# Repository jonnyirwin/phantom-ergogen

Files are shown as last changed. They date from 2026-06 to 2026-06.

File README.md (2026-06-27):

> ⚠️ **Work in progress — do not build this yet.** The PCB, case, and firmware have not been validated against a physical build. Things will change, things may be wrong. Watch the commits if you want to follow along, but don't order boards from these files yet.

# Eidolon

> **eidolon** /aɪˈdoʊlɒn/ *noun*
> An idealized image; a phantom or spectre of a person or thing.
> — from Greek εἴδωλον *(image, idol, phantom)*

---

A small column-staggered wireless split keyboard. 30 keys (5×3 + 2 thumb per half), Kailh Choc v1 switches, Seeed XIAO nRF52840 BLE, Totem-style clamshell case. Both halves are independent wireless units — no TRRS cable.

## Built on the shoulders of

| Keyboard | Role in this project |
|---|---|
| [**Phantom**](https://github.com/davidphilipbarr/Phantom) by davidphilipbarr | PCB layout source — key positions reverse-engineered from `lephantom.kicad_pcb`; board outline traced from the original `Edge.Cuts`. Eidolon matches the original key centres to < 0.15 mm. |
| [**TOTEM**](https://github.com/GEIGEIGEIST/TOTEM) by GEIGEIGEIST | Case design reference — switch hole dimensions, keycap recess depth, clamshell geometry, and hot-swap socket pocket profiles from the Totem STEP file; the XIAO BLE SMD footprint (`pcb/footprints/xiao_ble.js`) is adapted from Totem's `xiao-ble-smd-cutout`. |
| [**Rufous**](https://github.com/jcmkk3/trochilidae/) by jcmkk3 | Diode placement — diodes sit in each Choc south LED cutout following the Rufous approach. (`pcb/footprints/xiao_pogo.js`, a pogo-pin XIAO mount adapted from Rufous, is kept as an unused alternative to the SMD footprint.) |

## PCB

| Left half | Right half |
|---|---|
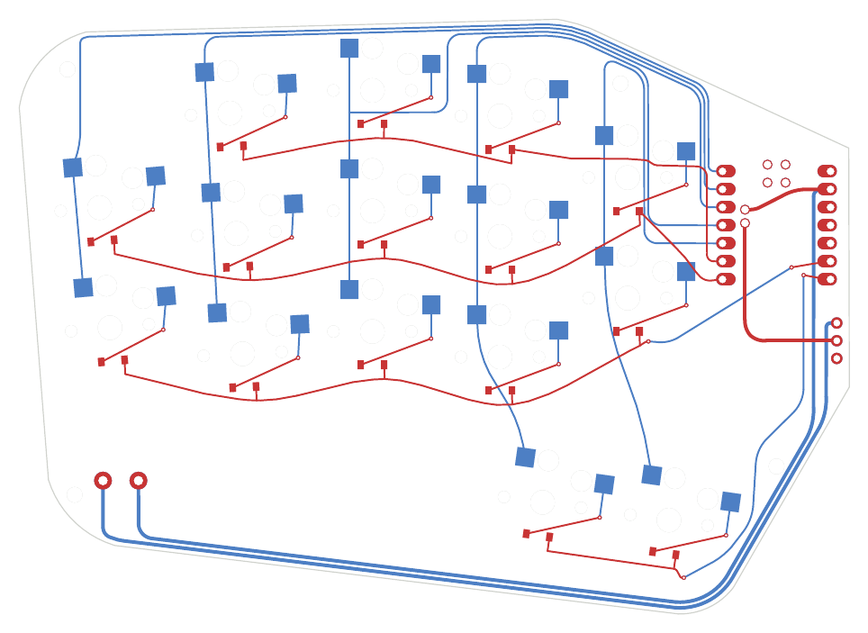
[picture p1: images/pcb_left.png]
Left PCB
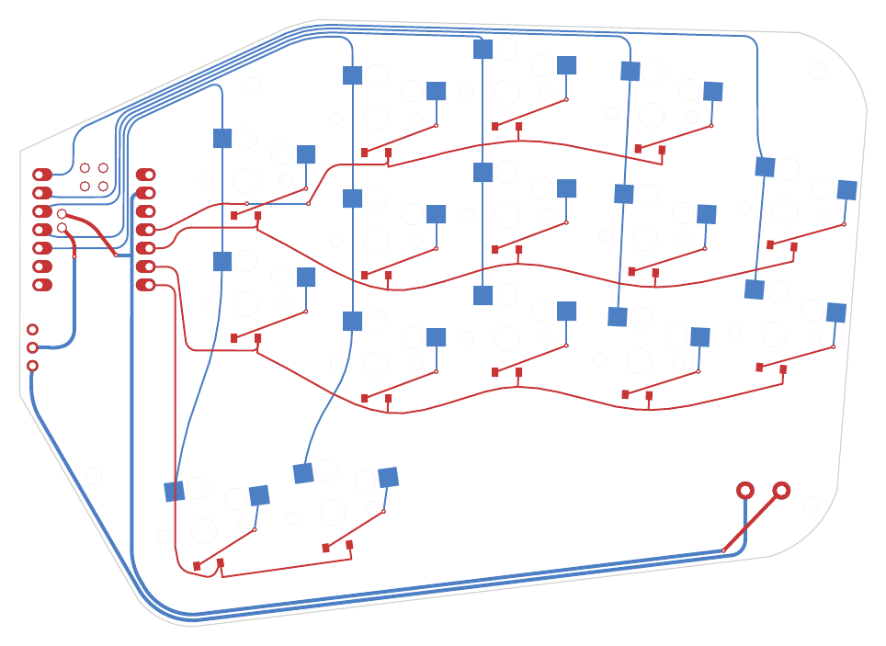
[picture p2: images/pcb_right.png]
Right PCB
|  |  |

## Case

| Top — left | Top — right |
|---|---|
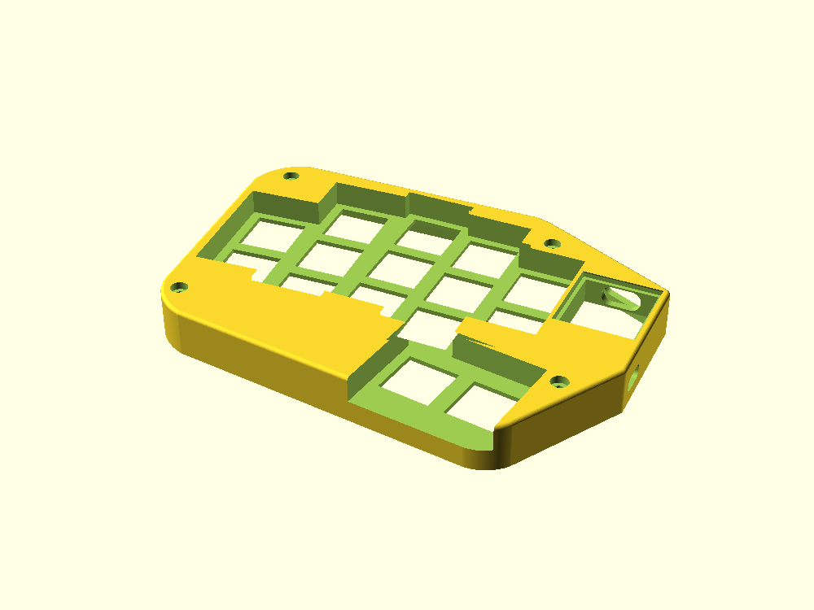
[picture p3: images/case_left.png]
Case top left
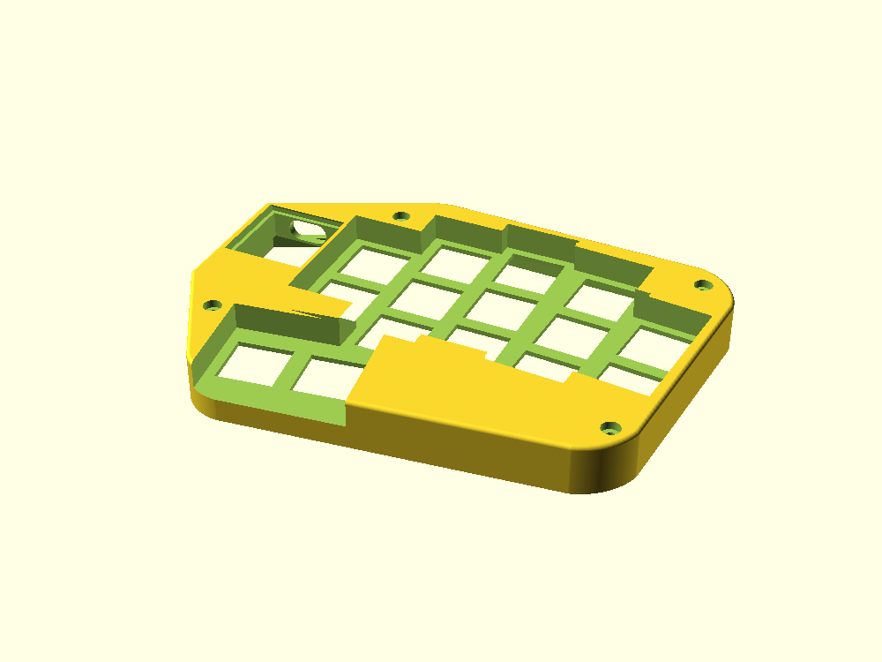
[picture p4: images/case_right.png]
Case top right
|  |  |

| Bottom — left | Bottom — right |
|---|---|
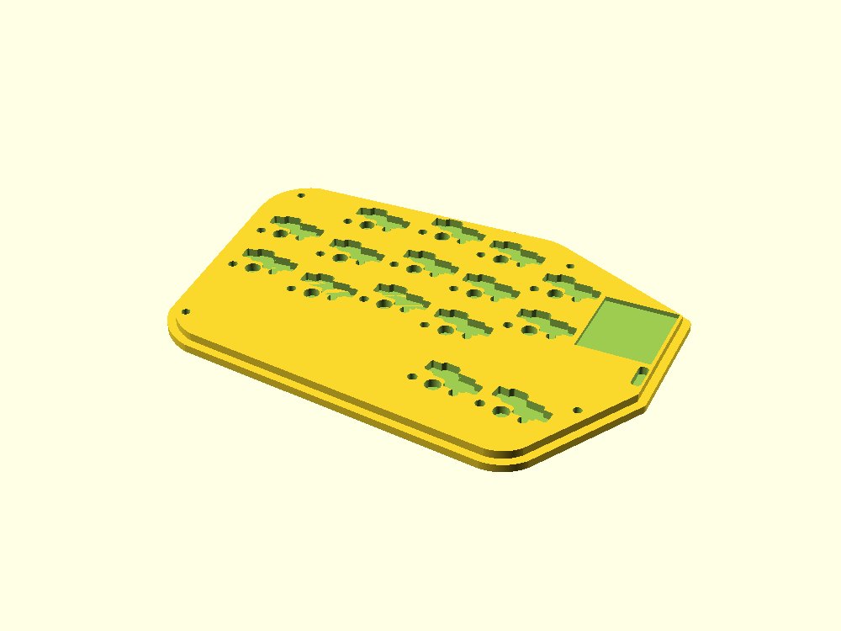
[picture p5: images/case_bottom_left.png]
Case bottom left
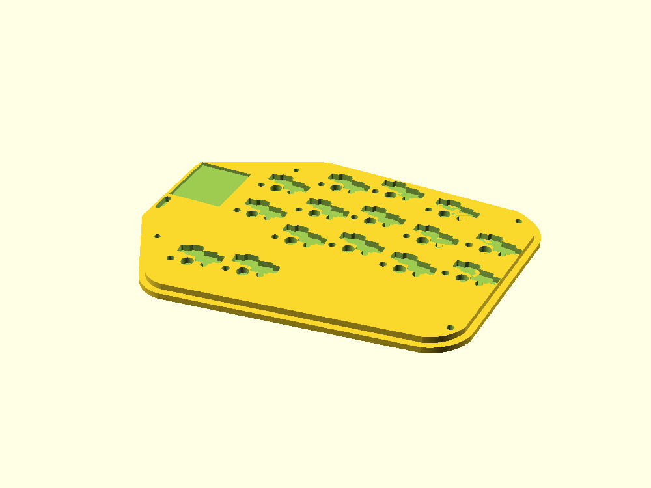
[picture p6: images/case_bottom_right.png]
Case bottom right
|  |  |

---

## Repository layout

```
pcb/              Ergogen source + routed KiCad files + gerbers
  eidolon.yaml      Ergogen config (geometry + nets)
  footprints/       custom Ergogen footprints
  build.js          local build wrapper (injects footprints)
  eidolon_left.kicad_pcb   routed left half
  eidolon_right.kicad_pcb  routed right half
  eidolon_left_gerbers.zip
  eidolon_right_gerbers.zip

case/             OpenSCAD case design
  eidolon_case.scad        top shell (both halves via -D right=true)
  eidolon_case_bottom.scad bottom shell
  stl/                     pre-generated STL files
```

---

## PCB build (Ergogen)

Custom footprints live in `pcb/footprints/`, so use the wrapper rather than the ergogen CLI directly:

```sh
cd pcb
npm install       # once
node build.js     # -> pcb/output/
```

Outputs land in `pcb/output/`:
- `outlines/board_left.svg|dxf`, `board_right.svg|dxf` — board perimeters
- `pcbs/eidolon_left.kicad_pcb`, `eidolon_right.kicad_pcb` — both halves, footprints + nets placed (no routes)

On **ergogen.xyz**, paste each file in `pcb/footprints/` into the web app's Footprints section under its filename (e.g. `reset_button`); `eidolon.yaml` then works as-is.

### Layout

```
 pinky  ring  middle index inner
   ·    top    top   top   ·       (pinky has no top row; inner has no bottom)
 home  home   home  home  upper
 bot   bot    bot   bot   lower
                  thumbL thumbR    (-8°)
```

Pinky splayed 5°, ring splayed 3°; other columns straight. Choc spacing: 18 mm columns, 17 mm rows.

### Wiring — COL2ROW diode matrix (XIAO BLE)

Each half is a fully independent wireless unit (own XIAO + battery, no TRRS), so the two halves carry **independent pin maps**. The columns are identical; the rows are assigned per half to keep each MCU's fan-out clean.

| Matrix | Net | XIAO pin (left) | XIAO pin (right) |
|---|-----|---|---|
| pinky col  | C0 | D0 | D0 |
| ring col | C1 | D1 | D1 |
| middle col | C2 | D2 | D2 |
| index col  | C3 | D3 | D3 |
| inner col  | C4 | D4 | D4 |
| top row | R0 | D5 | D10 |
| home row | R1 | D6 | D9  |
| bottom row | R2 | D8 | D8  |
| thumb row  | R3 | D7 | D7  |

On the right half all four rows sit on the matrix-facing `D7`–`D10` edge (`D5`/`D6` spare), so only the five columns cross the MCU — the physical minimum. **The two halves therefore need different `MATRIX_ROW_PINS` in firmware.**

Power: battery + → `RAW_BATT` → slide switch → `BATT` → XIAO `B+`; battery − → GND.

> **Verify before fab:** the XIAO pad→pin mapping lives in `pcb/footprints/xiao_ble.js` (surface-mount, mounted **face-up** over the PCB). It was corrected and checked against the XIAO datasheet and the TOTEM `xiao-ble-smd-cutout` footprint — re-confirm before ordering.

### Mirrored halves, not reversible

The original Phantom is a single reversible PCB flipped for both hands. Eidolon generates a true left and right board. Because each half is an independent wireless unit with its own firmware, the halves do **not** share a pin map — the right half's `MATRIX_ROW_PINS` differ from the left's (see the per-half table above).

---

## Case (OpenSCAD)

`case/eidolon_case.scad` is the top shell for both halves. The right half is the left mirrored (`-D right=true`).

```sh
openscad -o case/stl/eidolon_case_top_left.stl  case/eidolon_case.scad
openscad -D right=true -o case/stl/eidolon_case_top_right.stl  case/eidolon_case.scad
openscad -o case/stl/eidolon_case_bottom_left.stl  case/eidolon_case_bottom.scad
openscad -D right=true -o case/stl/eidolon_case_bottom_right.stl  case/eidolon_case_bottom.scad
```

Pre-generated STLs are in `case/stl/`.

Top shell features: keycap recess field, stepped 13.8 mm Choc plate holes, XIAO pocket with acrylic window rebate + USB-C cutout, battery pocket, power-switch wall slot, M2 bolt pockets.

### Bottom shell

`case/eidolon_case_bottom.scad` nests inside the top from below. Geometry:

- z ∈ [−2.0, 0]: exterior plate (`floor_t` = 2.0 mm) matching the top case outer footprint
- z ∈ [0, 2.1]: nesting lip; PCB rests on the lip top at z = 2.1
- Per-switch hot-swap socket pockets cut into the lip — traced from the Kailh PG1350 socket silkscreen (plastic body **plus** both SMD pad rectangles), inflated by `socket_clr` = 0.6 mm
- Choc plastic-pin, power-switch-leg, and XIAO underside-joint clearance pockets in the lip
- M2 hex nut pockets (4.0 mm AF × 1.8 mm) at the four bolt positions
- Four Ø8.4 × 1.8 mm bumpon pockets in the underside (≥7.5 mm clear of the nut pockets)

### Mounting hardware

| Part | Spec | Count |
|---|---|---|
| Socket cap bolt | M2 × 12 mm | 4 per half |
| Hex nut | M2 (4.0 mm AF) | 4 per half |

### MCU acrylic window

Cut a piece of 1.5 mm clear acrylic to drop into the XIAO rebate:

| Dimension | Size |
|---|---|
| Width | 20.3 mm |
| Length | 22.8 mm |
| Thickness | 1.5 mm |

Angle the acrylic, slip the +y edge under the square lip (lip A), press the −y edge down past the chamfered lip (lip B). Remove the bottom shell to access the MCU.

---

## Firmware

ZMK firmware for the Eidolon is available at [jonnyirwin/zmk-keyboard-eidolon](https://github.com/jonnyirwin/zmk-keyboard-eidolon).

---

## Deviations from the original Phantom

- **Mirrored L/R** instead of a single reversible board.
- **BLE only** — XIAO nRF52840, COL2ROW diode matrix, battery + slide switch; Pro Micro and TRRS removed.
- **Diodes top-side**, in each Choc south LED gap — hotswap sockets are the only underside component.
- **Trackball omitted.**
- Board outline is the original `Edge.Cuts` polygon with 1.5 mm corner fillets.

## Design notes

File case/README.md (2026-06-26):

# Eidolon Case

> **Warning: the changes listed below have not yet been physically verified. Print and test before ordering in quantity.**

## Changes from original design

### Bottom shell — bumpon pockets

Four 8.4mm diameter × 1.8mm deep pockets added to the bottom face for standard 8mm rubber bumpons. Positions (KiCad coords):

| Location | Position |
|---|---|
| Upper-right (MCU corner) | [141, 38] |
| Lower-right (thumb cluster) | [125, 91] |
| Upper-left | [50, 28] |
| Lower-left | [52, 84] |

All positions have ≥7.5mm clearance from nut pocket edges. The pocket depth matches the nut pockets (`m2_nut_h` = 1.8mm), leaving 0.2mm of floor material below (`floor_t` = 2.0mm).

### Reverted: thicker floor / deeper bolt-head pockets

An earlier revision raised `floor_t` 2.0 → 2.8mm (and `m2_head_h` 2.0 → 3.3mm to keep an M2×12 bolt flush) over a JLC thin-wall flag on the 0.2mm ceiling above the nut pockets. A resin-printed sample showed the thin walls print fine, so both values are reverted to the original design. The bottom floor is back to 2.0mm and M2 bolt heads sit flush with the deck.

## Fit fixes from the resin sample

A resin-printed sample confirmed the top-case switch recesses, M2 bolt recesses/holes
and PCB fit are all good. The following mating features were too tight or missing
clearance and have been corrected (case geometry only — the PCB is unchanged). All
new clearances are biased generous for easy, no-force assembly.

### Bottom shell

- **Hot-swap socket pockets** — the pocket was traced from the socket's *plastic*
  silkscreen only; the two metal SMD solder tabs overhang it by ~2.6mm at each end
  and had no clearance (the socket wouldn't seat). The pocket now cuts the plastic
  body **plus** both pad rectangles, and `socket_clr` is 0.3 → **0.6mm**.
- **Choc v1 plastic-pin pockets** (`switch_pin_pockets`) — new clearance for the
  central pole (Ø4.0) and two locating legs (Ø2.4) that poke below the PCB into the
  lip; previously absent.
- **Power-switch leg pockets** (`power_leg_pockets`) — new clearance slot for the
  three trimmed/soldered through-hole legs below the PCB.
- **XIAO underside-joint pocket** (`xiao_underside_pocket`) — shallow 1.2mm recess
  in the lip under the XIAO so its castellation fillets and the BAT/GND access-hole
  solder joints don't bear on the solid lip.

### Top shell

- **XIAO cavity** — was `20.0 × 17.5mm`, *smaller than the 21.0 × 17.78mm board*.
  Now board size + `xiao_clr` 0.4 → **0.6mm**/side (≈ 19.0 × 22.2mm window).
- **USB-C cutout** — was tight; now **+1.5mm wide** (9.0 → 10.5) and **+1.5mm tall**
  (4.0 → 5.5). Bottom edge unchanged, so the lip below stays ~1.75mm.
- **Power-switch body** — the visible rounded slot in the wall is unchanged (8 × 4mm).
  The switch body (just over 9mm wide, overhanging the PCB edge ~0.5mm) wouldn't fit,
  so a separate internal `power_body_pocket` (11mm) clears it; it reaches into the
  wall for the overhang and **merges with the XIAO cavity** (no dividing wall — the
  body and XIAO drop into one continuous opening, which also eases insertion). The
  body sits below the acrylic rebate, so the cover's top retention lip is preserved.

### Assembly notes (no case change)

- **XIAO** mounts flush on the PCB top via **castellated edge half-holes** (solder at
  the board edge, no under-board reflow). Its underside **BAT+/BAT− pads must be
  soldered up through the PCB access holes** beneath them — this completes the
  battery/charge path (the copper routing to the switch and battery pads is already
  present).
- **Battery**: solder the LiPo leads to the two battery pads (+ = RAW_BATT,
  − = GND, 5mm pitch). No jumper to the XIAO is needed.

## Remaining known issues (unresolved)

- `plate_t16 = 0.75mm` — the thin switch plate counterbore section under each switch hole. May be flagged by JLC depending on print process.
- `lip_t = 0.6mm` — acrylic retention lips on the XIAO cover slot. Thin for FDM; may need increasing if not printing in resin.

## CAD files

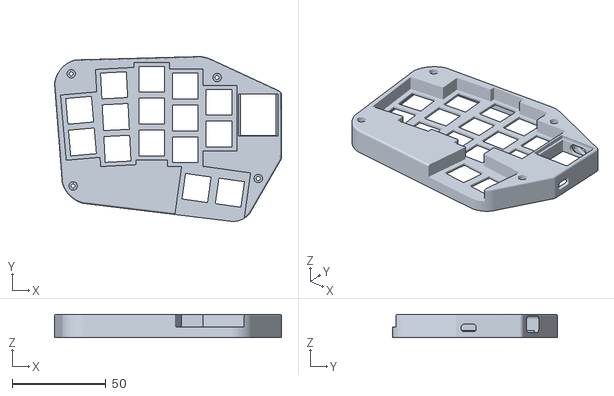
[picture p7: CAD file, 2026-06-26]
case/stl/eidolon_case_top_left.stl
121.4 x 88.2 x 12.5

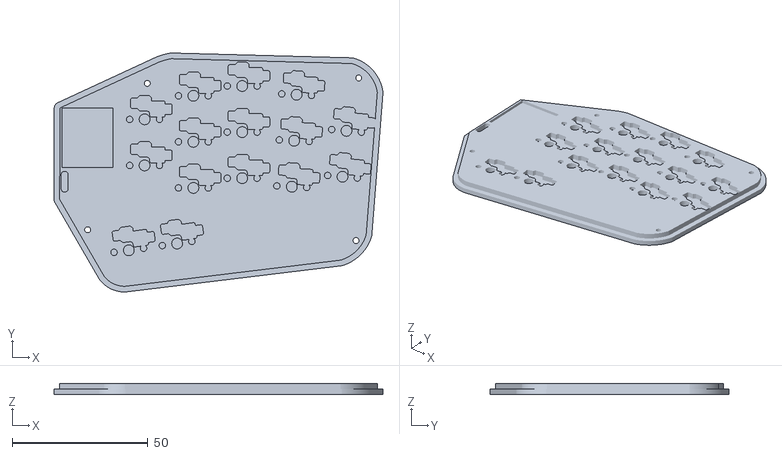
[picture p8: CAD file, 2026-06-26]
case/stl/eidolon_case_bottom_right.stl
121.4 x 88.2 x 4.10

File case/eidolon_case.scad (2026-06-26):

// Eidolon case — BOTH halves (left geometry; right = mirrored build).
// Outline from the PCB Edge.Cuts of lephantom.kicad_pcb (6 lines + 5 arcs,
// exact mm coordinates) plus the two routing reliefs now carried by BOTH
// ergogen PCBs (P1/P2 top edge -0.3mm, P10/P11 pinky edge -0.7mm), so the two
// boards are exact mirror images and one case design fits both. The case
// footprint is the PCB outline grown outward by (gap + wall) so the PCB drops
// inside the walls:
//   gap  = 0.15mm clearance between PCB edge and inner wall
//   wall = 2.0mm  case wall thickness
// then extruded. This pass produces the solid outer shape only.
//
//   openscad -o eidolon_case_top_left.stl  case/eidolon_case.scad
//   openscad -D right=true -o eidolon_case_top_right.stl case/eidolon_case.scad
//
// Right-half fit (verified against the routed ergogen boards): every
// footprint origin mirrors exactly (x_left + x_right = 170, same y), and the
// four case bolts ARE the PCB mounting holes. The XIAO keeps its orientation
// under the PCB mirror, but its position mirrors and the pocket/USB cutout
// are symmetric about the pocket axis, so the mirrored case still fits; the
// power switch flips orientation but its body centre and actuator height are
// unchanged, so the mirrored wall slot lines up.
right = true;   // build the right-half case (mirror of the left)

gap    = 0.15;   // PCB-to-inner-wall clearance (per side)
wall   = 2.0;    // case wall thickness
height = 12.5;   // extrusion depth (mm) — matches Totem top shell
switch = 13.8;   // Choc switch plate cutout (mm square) — Kailh spec / Totem STEP
// Per-column keycap recess. Depth/corner from Totem STEP; opening sized to the
// keycap (not the switch) so caps drop in without catching. At 18mm column pitch
// an 18mm cap leaves no rib, so adjacent column recesses merge into field pockets
// (as on the Totem, whose real recesses are big multi-column pockets).
recess_d = 6.85; // recess depth from top (rim->switch-plate in Totem)
keycap_x = 18.0; // keycap footprint, horizontal
keycap_y = 17.0; // keycap footprint, vertical
key_clr  = 0.5;  // extra clearance per side so caps don't catch
recess_r = 0;  // recess corner fillet
// Widen the recess on the RIGHT of the two leftmost columns (pinky+ring) by
// widen_f, extending them toward the next column to close the inter-column ribs.
// Top switches of the pinky+ring columns (the ones bordering the ribs); the
// bottom switch of each column (9, 11) is left at normal width.
widen_keys = [4, 1, 6];        // pinky-top, ring-top, ring-middle
widen_f    = 0.25;             // +25% width, added entirely on the right
// Stepped switch hole + plate (Totem STEP): below the recess floor sits a thin
// plate carrying the switch. The hole is 13.8mm for plate_t13 then opens to a
// 16mm counterbore for plate_t16; below the plate is a cavity for the PCB.
plate_t13 = 1.2;   // 13.8mm hole depth (upper, switch clips here)
plate_t16 = 0.75;  // 16mm counterbore depth (lower)
cbore     = 16.0;  // counterbore size
// derived z-levels (z=0 bottom, z=height top) — defined here so usb_z0 can use them
plate_top = height - recess_d;                 // recess floor / plate top (5.65)
plate_bot = plate_top - plate_t13 - plate_t16; // plate underside (3.70)
// XIAO BLE microcontroller — walled pocket on the right, a hole straight through
// the case (separate from the keycap recess). At the top (-y) end the slanted
// outer wall is flattened by a rounded-rectangular recess, and the USB-C socket
// cutout pierces that flat into the pocket. The PCB right edge is grown by
// pcb_pad (see outline) so the pocket has board under it + real walls.
xiao_l   = 21.0;           // board length (long axis, vertical / y) — footprint outline
xiao_w   = 17.8;           // board width (x) — footprint outline
xiao_clr = 0.6;            // clearance per side inside the pocket
xiao_pos = [137.0, 44.0];  // pocket center, KiCad coords — up near the top angle
xiao_rot = 0;              // deg; 0 = level with the right edge
// USB-C side: a rounded-rect recess cut into the top-right wall makes a flat
// face usb_wall in front of the pocket; the socket cutout goes through it.
flat_w   = 14.0;           // flat recess width  (x)
flat_h   = 9.0;            // flat recess height (z)
flat_r   = 2.0;            // flat recess corner radius
usb_wall = 2.0;            // wall left between the flat face and the pocket
usb_w    = 10.5;           // USB-C cutout width  (+1.5 from 9.0)
usb_h    = 5.5;            // USB-C cutout height (+1.5 from 4.0); lip below = 1.75mm
// SMD-mounted XIAO (castellated on PCB top): XIAO board sits on plate_bot with
// its own 1.0mm thickness, then the USB-C connector body extends ~3.16mm above
// that. Connector top is at plate_bot + 1.0 + 3.16 = plate_bot + 4.16. Place
// the cutout bottom 0.3mm below the XIAO PCB top to clear the connector body.
usb_z0   = plate_bot + 0.7;
// Acrylic cover over the XIAO through-hole: shallow rebate in the top deck,
// acrylic drops in flush with the deck top and rests on a ledge round the
// pocket. With SMD mount there's no MCU bump, so the rebate sits in the deck.
acrylic_t     = 1.5;       // acrylic thickness
acrylic_ledge = 1.0;       // ledge each side (rebate footprint > pocket footprint)
// Retention lips: deck material above the acrylic on the +/-y short ends that
// overhangs by lip_overhang, capturing the acrylic. One-time install: angle
// the acrylic to slip one short edge under one lip, then bow the acrylic
// slightly to push the other short edge past the second lip.
lip_t       = 0.6;        // lip vertical thickness (~3 print layers at 0.2mm)
lip_overhang= 0.8;        // lip A inward projection (full flat); lip B same width
                          // but flat for lip_b_flat with the rest chamfered.
lip_b_flat  = 0.4;        // lip B's flat retention width at the inner end
                          // (lip_overhang - lip_b_flat = chamfer width)
// Battery pocket — 301230 LiPo cell (3.0 x 12 x 30 mm) sits ON TOP of the PCB
// in the empty palm-rest area, hidden between the PCB and the underside of the
// deck. Pocket is cut UPWARD from plate_bot through the plate into the deck so
// the cell drops in from below before the PCB is seated; wires bend up to F.Cu
// pads on the PCB top (5mm apart, see footprints/battery.js). Bottom of the
// pocket is open to the under-PCB cavity (which the bottom shell will close).
bat_pos    = [59.625, 80.0]; // KiCad — palm-rest area, clear of every keycap pad
bat_rot    = 0;              // long axis along x (-90 = along y)
bat_x      = 38.75;          // pocket: 301230 cell (30) + 0.5 at +x + 8.25 wire
                             // well at -x. The well must hold the pad pair's
                             // 8.5mm copper span (TOTEM 5mm pitch, 2.5mm pads):
                             // moving the pads instead doesn't work — east puts
                             // pad-2 solder under the cell (0.25 margin), west
                             // pokes pad 1 out the wall. -x wall at 40.25 keeps
                             // 0.5 to pad-1 copper and 1.15 to the BL bolt shaft
bat_y      = 14.0;           // pocket width (cell 12 + 1mm each side)
bat_depth  = 3.5;            // cell + 0.5 clearance above plate_bot
// MSK-12D19 power switch — through-hole SPDT on the PCB right edge with the
// actuator overhanging. The case needs a slot in the right wall for the
// actuator/slider; sized for 1.5mm slider travel + clearance.
sw_pos   = [145.5, 60.27]; // switch centre, KiCad — matches ergogen power placement
sw_z     = plate_bot + 1.5;// slot vertical centre = actuator height above the PCB
// The switch body is just over 9mm wide along the wall and overhangs the PCB edge
// by 0.5mm, so the slot must clear the full body width — wider than the gap to the
// XIAO cavity. The pocket therefore MERGES into the XIAO cavity (no dividing wall).
// The body sits at z = [plate_bot, ~plate_bot+4], below the acrylic rebate, so the
// cover's top retention lip is preserved.
sw_slot_w = 8.0;           // visible actuator slot width (y) — rounded, original size
sw_slot_h = 4.0;           // slot height (z) — original; the side hole itself was fine
sw_slot_inward = 5.0;      // how much the slot extends into the case body (-x)
// The switch body is just over 9mm wide and overhangs the PCB edge ~0.5mm. It's
// cleared by a separate INTERNAL body pocket (power_body_pocket) that stays inboard
// of the outer wall — so the visible slot keeps its rounded look — and whose flat
// -y edge overlaps the XIAO cavity so the two voids merge without a coincident fin.
sw_body_w = 11.0;          // body 9.2 + clearance; flat -y edge (54.77) overlaps the
                           // XIAO cavity edge (55.1) by ~0.33mm at every z
sw_body_h = 4.5;           // body height above the PCB top
// M2 socket-cap case bolts at 4 corners (KiCad coords). Head sinks into a
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

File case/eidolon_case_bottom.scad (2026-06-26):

// Eidolon case — BOTTOM SHELL.
// Nests inside eidolon_case.scad. Sits below the PCB and pushes it up against
// the top case's plate. Shares outline / switches / bolts / plate_bot with
// the top SCAD via `include` (SUPPRESS_TOP=true skips the top render).
//
//   openscad -o eidolon_case_bottom_left.stl case/eidolon_case_bottom.scad
//
// Geometry (z-up, KiCad y-down — final mirror flips y):
//   z ∈ [-floor_t, 0] : exterior plate, outer = outline + gap + wall, matches
//                       the top case outer so the seam at z=0 is flush.
//   z ∈ [0, lip_h]    : nesting lip, outer = outline + gap - fit_clr, slips
//                       into the top case cavity from below.
//   lip_h = plate_bot - pcb_t = 2.10mm  (PCB underside rest plane).
// Cutouts:
//   - Kailh PG1350 hot-swap socket pockets at each switch — TOTEM silkscreen
//     outline (Z-shape, two bulges). The pockets cut all the way through the
//     lip (z=0 → z=lip_h) so a 1.8mm-tall socket fits, but the exterior
//     plate seals them at the bottom, so the sockets are not visible from
//     outside. Socket bottom ends ~0.3mm above the floor top.
//   - M2 hex-nut pockets in the bottom face at the four corner bolts.
//   - M2 shaft holes through the whole shell.

SUPPRESS_TOP = true;
include <eidolon_case.scad>;

// === bottom-shell dimensions ===
pcb_t           = 1.6;                 // PCB thickness
floor_t         = 2.0;                 // exterior plate below z=0 (2mm min wall)
lip_h           = plate_bot - pcb_t;   // 2.10mm — nesting lip top = PCB underside
fit_clr         = 0.1;                 // lip-to-top-case-cavity slip clearance

// Kailh PG1350 hot-swap socket body outline in switch local frame, traced from
// TOTEM's Kailh_socket_PG1350_optional.kicad_mod silkscreen — a Z-shape with
// two rectangular bulges (one around each SMD pad) connected by curves. Pads
// are at (-3.275, -5.95) and (8.275, -3.75). The polygon hugs the body; a
// small inflation by socket_clr is applied at use to give plastic clearance.
socket_outline = [
    [-2.0,    -4.2  ], [-2.0,    -7.7  ],
    [-1.5,    -8.2  ], [ 1.5,    -8.2  ],
    [ 2.0,    -7.7  ], [ 2.0,    -6.7  ],
    [ 2.1464, -6.3464],                     // arc midpoint (lower inner corner)
    [ 2.5,    -6.2  ], [ 7.0,    -6.2  ],
    [ 7.0,    -1.5  ], [ 2.5,    -1.5  ],
    [ 2.5,    -2.2  ],
    [ 2.0607, -3.2607],                     // arc midpoint (upper inner corner)
    [ 1.0,    -3.7  ], [-1.5,    -3.7  ]
];
socket_clr = 0.6;  // inflate the outline by this much for socket plastic+metal slop

// M2 hex nut: 4.0mm across flats. Hex circumradius = 4/√3 ≈ 2.31, plus slack.
m2_nut_af = 4.0;
m2_nut_h  = 1.8;   // nut thickness; pocket depth from the bottom face upward

module bottom_body()
    union() {
        translate([0, 0, -floor_t])
            linear_extrude(floor_t)
                offset(r = gap + wall) polygon(outline);
        linear_extrude(lip_h)
            offset(r = gap - fit_clr) polygon(outline);
    }

// === clearance pockets cut into the lip (z = 0 .. lip_h) ===
// All of the below pierce the full lip height so parts protruding below the PCB
// fit; the exterior floor seals the cuts from outside. Straight (no chamfer) —
// the fit is set by clearance alone.

// Hot-swap socket pocket footprint: the hand-traced plastic body PLUS the two
// metal SMD solder tabs (2.6mm sq at the pad centres), which overhang the plastic
// by ~2.6mm at each end and previously had no clearance. socket_clr inflates it.
// The sockets do NOT mirror on the right-half PCB, but the footprint is chiral, so
// for the right build the profile is mirrored LOCALLY and the global mirror([1,0,0])
// cancels it — leaving the pocket in the physical socket's chirality.
sock_pad_d = 2.6;
sock_pads  = [[-3.275, -5.95], [8.275, -3.75]];
module socket_full() {
    polygon(socket_outline);
    for (p = sock_pads) translate(p) square(sock_pad_d, center = true);
}
module socket_2d() {
    if (right) mirror([1, 0]) offset(r = socket_clr) socket_full();
    else                      offset(r = socket_clr) socket_full();
}
module socket_pockets()
    for (s = switches)
        translate([s[0], s[1], 0])
            rotate([0, 0, -s[2]])
                linear_extrude(lip_h + 0.02) socket_2d();

// Choc v1 plastic protrusions poking below the PCB: central pole + two locating
// legs, on the switch y=0 axis. (The electrical pin holes sit inside the socket
// pocket already, so only these three plastic features need clearing.)
pole_d = 4.0;   // central pole Ø3.429 + clearance
leg_d  = 2.4;   // locating legs Ø1.702 + clearance
module switch_pins_2d() {
    circle(d = pole_d, $fn = 64);
    translate([ 5.5, 0]) circle(d = leg_d, $fn = 48);
    translate([-5.5, 0]) circle(d = leg_d, $fn = 48);
}
module switch_pin_pockets()
    for (s = switches)
        translate([s[0], s[1], 0])
            rotate([0, 0, -s[2]])
                linear_extrude(lip_h + 0.02) switch_pins_2d();

// MSK-12D19 trimmed-leg clearance: the 3 through-hole legs (2.5mm pitch along y)
// protrude below the PCB into the lip. Rounded slot at sw_pos; the global mirror
// handles the right build, as with power_slot().
module power_legs_2d()
    offset(r = 1.0) square([0.5, 5.5], center = true);   // -> 2.5 x 7.5 rounded
module power_leg_pockets()
    translate([sw_pos[0], sw_pos[1], 0])
        linear_extrude(lip_h + 0.02) power_legs_2d();

// XIAO underside solder-joint clearance: shallow recess in the lip top under the
// XIAO so the castellation fillets and the BAT/GND access-hole joints (soldered up
// through the PCB) don't bear on the solid lip. Leaves ~0.9mm of lip below.
xiao_uj_depth = 1.2;
module xiao_underside_pocket()
    translate([xiao_pos[0], xiao_pos[1], lip_h - xiao_uj_depth])
        rotate([0, 0, -xiao_rot])
            linear_extrude(xiao_uj_depth + 0.02)
                square([xiao_w + 1, xiao_l + 1], center = true);

// Hex nut pockets in the bottom face (z = -floor_t), m2_nut_h deep upward.
module nut_pockets()
    for (b = bolts)
        translate([b[0], b[1], -floor_t - 0.01])
            linear_extrude(m2_nut_h + 0.01)
                circle(r = m2_nut_af / sqrt(3) + 0.07, $fn = 6);

// Bolt shaft holes — all the way through so the bolt can engage the nut.
module bolt_shafts()
    for (b = bolts)
        translate([b[0], b[1], -floor_t - 1])
            linear_extrude(lip_h + floor_t + 2)
                circle(d = m2_shaft_d, $fn = 96);

// Bumpon (rubber foot) pockets — 8.4mm dia, on the bottom face.
// Same depth as the nut pockets (m2_nut_h), leaving 0.2mm of floor below.
bumpon_d     = 8.4;
bumpon_depth = m2_nut_h;
bumpons = [
    [141,  38],   // upper-right — MCU corner
    [125,  91],   // lower-right — thumb cluster corner
    [ 50,  28],   // upper-left  — 7.7mm from TL bolt, 9.5mm from top wall
    [ 52,  84],   // lower-left  — 7.5mm from BL bolt, 15mm from left wall
];

module bumpon_pockets()
    for (b = bumpons)
        translate([b[0], b[1], -floor_t - 0.01])
            linear_extrude(bumpon_depth + 0.01)
                circle(d = bumpon_d, $fn = 96);

module bottom_case()
    mirror([0, 1, 0])
        difference() {
            bottom_body();
            socket_pockets();
            switch_pin_pockets();
            power_leg_pockets();
            xiao_underside_pocket();
            nut_pockets();
            bolt_shafts();
            bumpon_pockets();
        }

// Preview: render top + bottom together for fit check. EXPLODED > 0 lifts the
// top by that many mm; 0 = fully assembled. `right` (from the included top
// SCAD, or -D right=true) mirrors the build for the right half:
//   openscad -D right=true -o eidolon_case_bottom_right.stl case/eidolon_case_bottom.scad
PREVIEW  = false;
EXPLODED = 6;

module bottom_build() {
    if (PREVIEW) {
        bottom_case();
        translate([0, 0, EXPLODED]) top_case();
    } else {
        bottom_case();
    }
}

if (right) mirror([1, 0, 0]) bottom_build();
else bottom_build();

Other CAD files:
case/stl/eidolon_case_top_right.stl
case/stl/eidolon_case_bottom_left.stl

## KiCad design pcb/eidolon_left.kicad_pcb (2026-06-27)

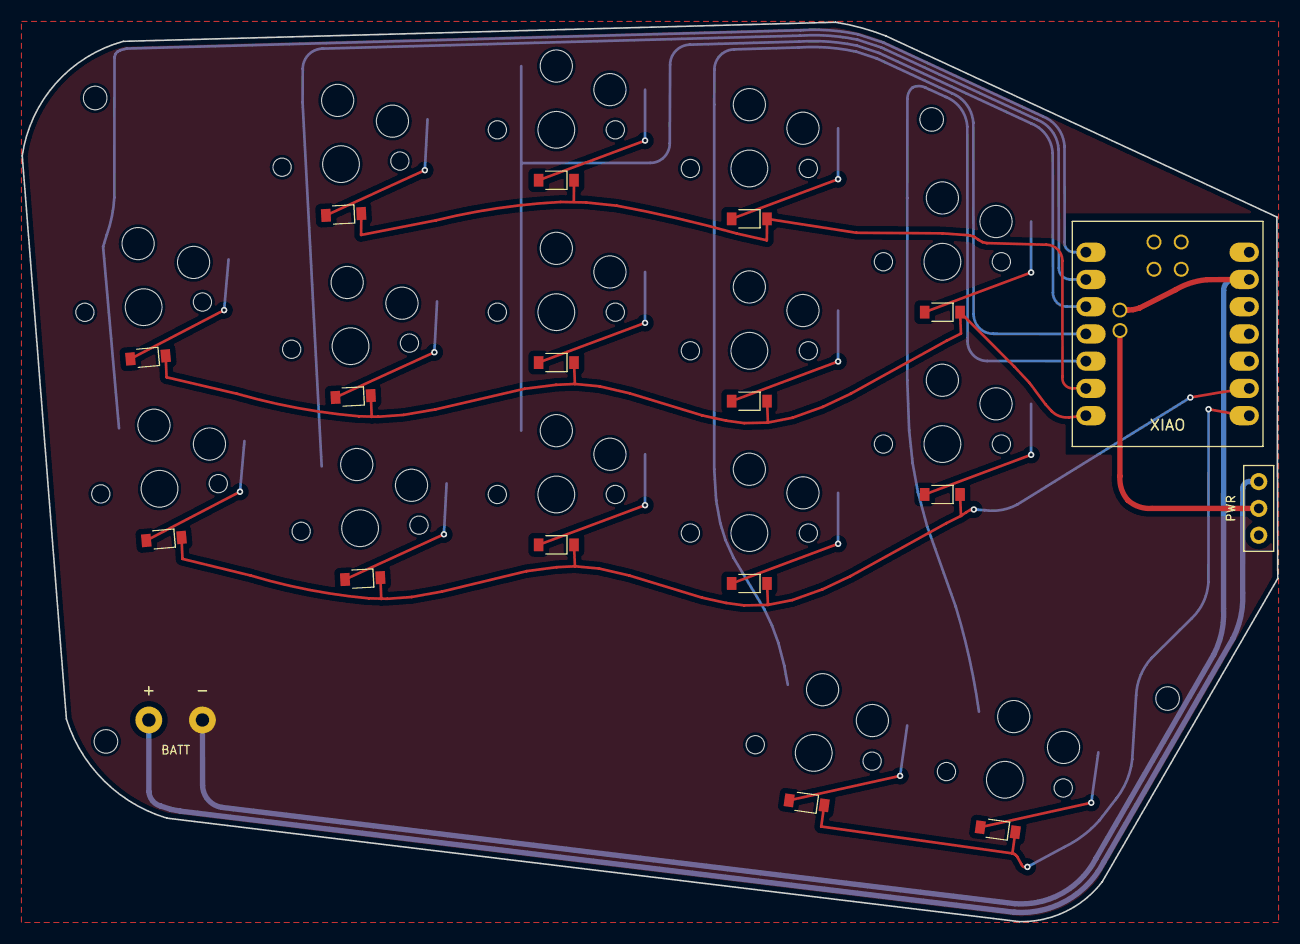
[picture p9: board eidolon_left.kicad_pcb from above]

Board: 2 copper layers, 117.1 x 83.9 mm, 37 parts (0 on the bottom side), 27 nets.

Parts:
BT1: battery_pads
D1, D2, D3, D4, D5, D6, D7, D8, D9, D10, D11, D12, D13, D14, D15: diode_sod123
MCU1: xiao_ble
MH1, MH2, MH3, MH4: mounting_hole_m2
S1, S2, S3, S4, S5, S6, S7, S8, S9, S10, S11, S12, S13, S14, S15: PG1350
SW1: power_switch_spdt

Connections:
BATT: MCU1.BAT, SW1.2
C0: MCU1.1, S12.1, S13.1
C1: MCU1.2, S9.1, S10.1, S11.1
C2: MCU1.3, S1.1, S2.1, S3.1
C3: MCU1.4, S4.1, S5.1, S6.1, S14.1
C4: MCU1.5, S7.1, S8.1, S15.1
GND: BT1.2, MCU1.13, MCU1.GND
R0: D3.2, D6.2, D11.2, MCU1.6
R1: D2.2, D5.2, D8.2, D10.2, D13.2, MCU1.7
R2: D1.2, D4.2, D7.2, D9.2, D12.2, MCU1.9
R3: D14.2, D15.2, MCU1.8
RAW_BATT: BT1.1, SW1.1
matrix_index_bottom: D4.1, S4.2
matrix_index_home: D5.1, S5.2
matrix_index_top: D6.1, S6.2
matrix_inner_bottom: D7.1, S7.2
matrix_inner_home: D8.1, S8.2
matrix_middle_bottom: D1.1, S1.2
matrix_middle_home: D2.1, S2.2
matrix_middle_top: D3.1, S3.2
pinky_pinky_bottom: D12.1, S12.2
pinky_pinky_home: D13.1, S13.2
ring_ring_bottom: D9.1, S9.2
ring_ring_home: D10.1, S10.2
ring_ring_top: D11.1, S11.2
thumb_left_thumb: D14.1, S14.2
thumb_right_thumb: D15.1, S15.2

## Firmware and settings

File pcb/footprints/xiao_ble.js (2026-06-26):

// Seeed XIAO BLE (nRF52840) surface-mount castellated footprint.
// Adapted from GEIGEIGEIST/TOTEM v0.3 "xiao-ble-smd-cutout.kicad_mod":
//   - 14 thru-hole oval pads at x=±7.62, 2.54mm pitch, drill 1mm with the
//     drill OFFSET 0.475 toward the board center -> half-holes for soldering
//     to the XIAO's castellated edge, while keeping a normal copper pad on
//     the inside that can route on either layer.
//   - 4 inner thru-hole pads near the USB end aligning with the XIAO's underside
//     SWD debug group (SWDIO / SWCLK / RESET / GND). Left UNCONNECTED here --
//     access holes only. (Verified against GEIGEIGEIST/TOTEM: these are the
//     debug pads, NOT the battery -- an earlier revision had this backwards.)
//   - 2 thru-hole pads at the side reaching the XIAO underside BAT + GND -- this
//     is the actual battery connection (cell -> power switch -> BATT -> here).
//
// Local frame: USB end at -y, far end at +y. XIAO is mounted FACE-UP on top
// of the keyboard PCB so component-side pins map directly (no x-mirror).
// The existing Phantom config uses rotate: 0, which puts the XIAO USB toward
// the KiCad -y direction (top-right of the source PCB) — this matches.
//
// Net mapping (face-up XIAO, USB at local -y):
//   left col  (x = -7.62), -y -> +y:  D0 D1 D2 D3 D4 D5 D6
//   right col (x = +7.62), -y -> +y:  5V GND 3V3 D10 D9 D8 D7
// The power pins (5V/GND/3V3) cluster at the USB end (-y); D7 is the far-corner
// pin, adjacent to D6 across the bottom edge. (An earlier revision had this
// column reversed -- D7 at the USB end, 5V at the far end -- which put VBUS on a
// matrix row and 5V/GND onto GPIOs. Fixed.)
module.exports = {
  params: {
    designator: 'MCU',
    side: 'F',
    P5V: { type: 'net', value: 'P5V' },
    GND: { type: 'net', value: 'GND' },
    P3V3: { type: 'net', value: 'P3V3' },
    BAT: { type: 'net', value: 'BAT' },
    D0: { type: 'net', value: 'D0' }, D1: { type: 'net', value: 'D1' },
    D2: { type: 'net', value: 'D2' }, D3: { type: 'net', value: 'D3' },
    D4: { type: 'net', value: 'D4' }, D5: { type: 'net', value: 'D5' },
    D6: { type: 'net', value: 'D6' }, D7: { type: 'net', value: 'D7' },
    D8: { type: 'net', value: 'D8' }, D9: { type: 'net', value: 'D9' },
    D10: { type: 'net', value: 'D10' }
  },
  body: p => {
    // castellated half-hole: drill offset 0.475mm toward board centre (+x for
    // left col, -x for right col), so the drilled cylinder breaks out as a
    // half-cylinder on the board edge.
    const cast = (name, x, y, net) => {
      const off = x < 0 ? '0.475 0' : '-0.475 0';
      return `(pad "${name}" thru_hole oval (at ${x} ${y} ${p.r}) (size 2.75 1.8) (drill 1 (offset ${off})) (layers *.Cu *.Mask) ${net})`;
    };
    // inner access hole: small thru-hole 1.397 dia, 1.016 drill
    const access = (name, x, y, net) =>
      `(pad "${name}" thru_hole circle (at ${x} ${y} ${p.r}) (size 1.397 1.397) (drill 1.016) (layers *.Cu *.Mask) ${net})`;
    return `
    (module xiao_ble (layer F.Cu) (tstamp 0)
      (descr "Seeed XIAO BLE (nRF52840) castellated SMT mount, TOTEM-style")
      (tags "xiao nrf52840 ble castellated")
      ${p.at}
      (fp_text reference "${p.ref}" (at 0 11 ${p.r}) (layer ${p.side}.SilkS) ${p.ref_hide} (effects (font (size 1 1) (thickness 0.15))))
      (fp_text value "" (at 0 0) (layer ${p.side}.SilkS) hide (effects (font (size 1 1) (thickness 0.15))))
      (fp_text user "XIAO" (at 0 8.5 ${p.r}) (layer ${p.side}.SilkS) (effects (font (size 1 1) (thickness 0.15))))
      ${'' /* board outline 17.78 x 21 mm */}
      (fp_line (start -8.89 -10.5) (end  8.89 -10.5) (layer ${p.side}.SilkS) (width 0.12))
      (fp_line (start -8.89  10.5) (end  8.89  10.5) (layer ${p.side}.SilkS) (width 0.12))
      (fp_line (start -8.89 -10.5) (end -8.89  10.5) (layer ${p.side}.SilkS) (width 0.12))
      (fp_line (start  8.89 -10.5) (end  8.89  10.5) (layer ${p.side}.SilkS) (width 0.12))
      ${'' /* left col (x = -7.62): D0..D6, USB end (-y) -> far end (+y) */}
      ${cast('1',  -7.62, -7.62, p.D0)}
      ${cast('2',  -7.62, -5.08, p.D1)}
      ${cast('3',  -7.62, -2.54, p.D2)}
      ${cast('4',  -7.62,  0,    p.D3)}
      ${cast('5',  -7.62,  2.54, p.D4)}
      ${cast('6',  -7.62,  5.08, p.D5)}
      ${cast('7',  -7.62,  7.62, p.D6)}
      ${'' /* right col (x = +7.62), USB end (-y) -> far end (+y): 5V GND 3V3 D10 D9 D8 D7 */}
      ${cast('14',  7.62, -7.62, p.P5V)}
      ${cast('13',  7.62, -5.08, p.GND)}
      ${cast('12',  7.62, -2.54, p.P3V3)}
      ${cast('11',  7.62,  0,    p.D10)}
      ${cast('10',  7.62,  2.54, p.D9)}
      ${cast('9',   7.62,  5.08, p.D8)}
      ${cast('8',   7.62,  7.62, p.D7)}
      ${'' /* SWD debug group on the XIAO underside near the USB end
            (SWDIO/SWCLK/RESET/GND). Left UNCONNECTED -- access holes only, not
            wired into the keyboard. NOTE: these are NOT battery pads. */}
      ${access('SWDIO',  -1.27, -8.572, '')}
      ${access('SWCLK',   1.27, -8.572, '')}
      ${access('RESET',  -1.27, -6.032, '')}
      ${access('DBG_GND', 1.27, -6.032, '')}
      ${'' /* Battery: the XIAO underside BAT pad + adjacent GND, at the side
            ~mid-board. The cell connects here via the power switch on BATT. */}
      ${access('BAT', -4.445, -0.317, p.BAT)}
      ${access('GND', -4.445, -2.222, p.GND)}
    )
    `;
  }
};

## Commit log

2026-06-21 feat(case): thicker bottom floor + bumpon pockets
    Increase floor_t 2.0 → 2.8mm so the wall above M2 nut pockets is 1.0mm
    (was 0.2mm, flagged by JLC). Add four 8.4mm-dia × 2mm-deep bumpon pockets
    on the bottom face at the case corners, clear of all nut pockets.
    Claude-Session: https://claude.ai/code/session_01FX4sqbnHaThXfgqPxsCZfz
    [eidolon_case_bottom.scad]
2026-06-21 feat(case): deepen bolt head pocket for M2×12 with floor_t=2.8mm
    Increase m2_head_h 2.0 → 3.3mm so an M2×12 bolt has its tip exactly
    flush with the case bottom and engages the full 1.8mm nut height.
    Head sits 1.3mm recessed below the deck surface.
    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
    [eidolon_case.scad]
2026-06-21 build(stl): regenerate all four case STLs
    Reflects deeper floor (floor_t 2.0→2.8mm), bumpon pockets, and deeper
    bolt head pockets (m2_head_h 2.0→3.3mm) for M2×12 compatibility.
    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
    [eidolon_case_bottom_left.stl, eidolon_case_bottom_right.stl, eidolon_case_top_left.stl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]
2026-06-21 docs(case): add README documenting design changes and known issues
    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
2026-06-26 fix(pcb): correct reversed XIAO right-column pinout; drop stale gerbers
    The xiao_ble footprint had its right castellated column reversed end-for-end:
    top->bottom was D7,D8,D9,D10,3V3,GND,5V instead of 5V,GND,3V3,D10,D9,D8(R3),D7(R2).
    This put VBUS-5V on the R2 matrix row, GND on R3, and tied real GPIOs D7/D8/D9 to
    5V/GND/3V3 -- dead bottom/thumb rows plus a 5V-on-GPIO path that can damage the
    nRF52840 on USB power. Verified against the XIAO datasheet and pad adjacency, and
    with KiCad DRC on the regenerated netlist. Affects both halves (right is asym:clone
    un-mirrored), so the single footprint edit fixes both.
    The committed gerbers were exported from the buggy boards, so they are removed; ne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
    [xiao_ble.js]
2026-06-26 feat(case): resin-sample fit fixes; revert thicker floor
    A resin-printed sample confirmed the switch recesses, M2 recesses/holes and PCB fit
    are good, and that the thin walls print fine -- so the earlier floor_t 2.0->2.8mm and
    m2_head_h 2.0->3.3mm changes are reverted to the original design (floor back to 2.0mm,
    bolt heads flush). Mating-feature corrections (case geometry only, PCB unchanged):
    - Hot-swap socket pockets now cut the plastic body PLUS both SMD pad tabs; socket_clr
    0.3 -> 0.6mm so the socket seats.
    - New Choc v1 plastic-pin pockets (pole + locating legs) and power-switch leg pockets
    for parts that poke below the PCB.
    - New XIAO underside-joint recess so castellation/BAT-GND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
    [eidolon_case.scad, eidolon_case_bottom.scad, eidolon_case_bottom_left.stl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]
2026-06-27 chore(claude): session state + decision addendum (faithful re-route progress)
    Left half re-routed to 0 DRC / 0 unconnected (whole-module keepout restored,
    explicit B.Cu GND margin rail, R2 crosses the rail on F.Cu). Right half 7->3
    violations: principled GND-inner/RAW-outer lanes, rail threads the C4/pad gap,
    and the topologically-forced GND<->RAW crossing resolved with one F.Cu hop at
    the battery end. Decision 001 addendum documents the mirrored-half via
    exceptions to the "no vias" ideal. Router source lives in ~/git/phantom-router
    (not under git); committed boards still the OLD buggy ones, not fab-ready.
    Claude-Session: https://claud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
2026-06-27 fix(pcb): land faithfully re-routed boards + gerbers (corrected pinout)
    Replace the old buggy routed boards with the re-routed eidolon_{left,right}
    from the phantom autorouter (~/git/phantom-router), built on the corrected
    XIAO right-column pinout. Both halves: 0 DRC violations, 0 unconnected.
    Whole-module GND pour keepout; explicit hand-shaped B.Cu GND margin rail;
    R2/R3 re-derived for the moved pinout (rail crossings on F.Cu, minimal vias);
    the mirrored right half's forced GND/RAW crossing and under-MCU access-pad
    jumper threaded with one via each. Re-exported gerbers (all layers + drill).
    Fab-ready.
    Claude-Session: https://claude.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
    [eidolon_left.kicad_pcb, eidolon_right.kicad_pcb]
2026-06-27 feat(pcb): per-half XIAO pin maps; declutter right-half routing
    Each half is an independent wireless unit, so the net->pin maps need not match.
    Give the right half its own map (all 4 rows on the matrix-facing D7-D10 edge:
    D7:R3 D8:R2 D9:R1 D10:R0; columns on D0-D4). The left keeps R0/R1 on D5/D6.
    This moves R0/R1 off the far MCU edge on the right, so they fan out directly
    east instead of crossing back over the MCU ("west-about" boxed routes). Only
    the 5 columns now cross under the MCU on the right (the physical floor). Both
    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
    [eidolon_left.kicad_pcb, eidolon_right.kicad_pcb]
2026-06-27 docs(readme): sync with re-routed PCB + reworked case
    - Regenerate all 6 renders (clean no-pour PCB traces; per-half case views;
    fix the previously mis-mirrored case_bottom_right).
    - Wiring table now per-half (independent pin maps); fix R2/R3<->D7/D8 swap;
    note the halves need different MATRIX_ROW_PINS.
    - Drop stale QMK direct-pin mirroring note (independent ZMK halves).
    - Point verify note at the footprint actually built (xiao_ble.js, face-up SMD);
    credit TOTEM for it, note xiao_pogo.js as the unused Rufous alternative.
    - Bottom shell: floor -0.9->-2.0mm, traced PG1350 socket pockets, added
    pin/leg/underside clearance pockets + bumpon pockets.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
